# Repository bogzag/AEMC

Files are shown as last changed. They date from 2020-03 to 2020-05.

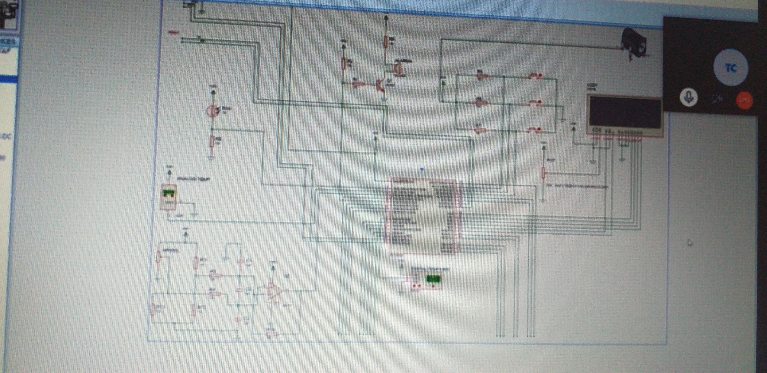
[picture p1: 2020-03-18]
PozeProiect/Schematic/20200318_112239.jpg

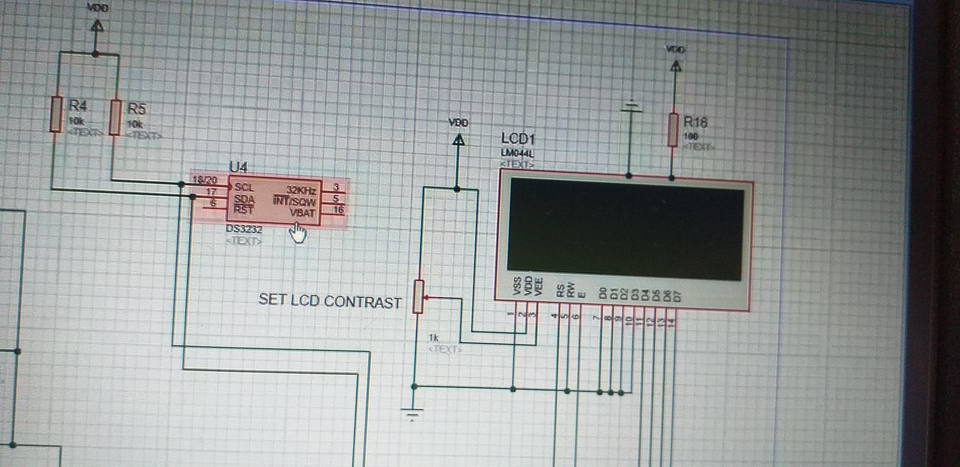
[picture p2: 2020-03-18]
PozeProiect/Schematic/20200318_110541.jpg

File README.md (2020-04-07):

# AEMC PROJECT:v:
The task is to create a meteo station (schematic, layout,code,hardware). 

Please upload your work in the correct section and add comments to avoid confusion between team members

Mention urgent tasks here and mark them with :exclamation:

Mark wrong info like this  ~~This info wrong my man~~

### Team members:sleeping:

@bogzag

@ClaudiaGitH

@alexandruf98

### Pt curs/proiect
(https://join.skype.com/lMuimAnFgpZ3?fbclid=IwAR00U5oWaqc2DzT4iKskiz9u4dI-uODVIiYZsmZv1TnuRMnrCDzAk37EaNk)

:exclamation: Layout+Code

### $ Lista de cumparaturi:
https://docs.google.com/spreadsheets/d/1xGkr67w3PWWBnmwl580I28Ox6pwAhuXMNzGf5ZXCvtU/edit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

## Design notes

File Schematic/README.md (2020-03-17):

# Schematic for AEMC PROJECT , done in PROTEUS v8.0

-All schematic versions must be done in Proteus version 8.0, newer versions might not be compatible

-Download and present the last uploaded version. Work only on the newer version of the schematic

-Add comments on changes, so all users know what issues are solved : 

## Task list:yum:
[ ]add changes after the project session

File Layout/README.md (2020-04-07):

# Layout for AEMC PROJECT, done in 

## Task list:yum:

- De finalizat partea cu senzorul de umiditate si amplificarea
- De ingrosat putin mai mult traseele (acum sunt 0.8 mm)

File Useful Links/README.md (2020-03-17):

# Useful Links for the project:paperclip:

Please mention if the resource is for a component or a tutorial, so we avoid wasting time wjile looking for info

## Components

https://www.olimex.com/Products/Modules/PIC-ICSP-Connector/ 

https://www.isweek.com/product/humidity-sensitive-resistor-hr202l_2691.html

https://cleste.ro/modul-usb-catre-ttl-cu-jumper.html

## Tutorials

https://exploreembedded.com/wiki/Serial_Communication_with_PIC16F877A

https://circuitdigest.com/microcontroller-projects/uart-communication-using-pic16f877a

https://www.youtube.com/watch?time_continue=35&v=idJEMYhrIfs&feature=emb_logo

## DataSheets

https://datasheets.maximintegrated.com/en/ds/DS1307.pdf

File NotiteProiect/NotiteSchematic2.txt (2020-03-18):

*Run Simulation
*We should create a simulation to see if all sensors
*A student per function
*Sa vedem care sunt valorile de rezistenta corespunzatoare starii de intuneric si lumina
max 5 v la luminanta maxima
nu trebie sa se satureze rezistenta R4 rezistenta mare
*Buzzer daca este functional la un curent de 0.5 miliamperi R6-un tranzistor cotr din microcontroler si tranzistorul sa aiba un buzzer in colector
*Putem incepe sa cream rutine soft
*Layoutul pt mufa de alimentare schimbat
*C-se opune variatilor rapide de tensiune
	-C2 : R4+fotorezis= divizor rezistiv
	-filtre blala frecventa de taiere 10 hz
	-o variatie lenta a luminii
	-o citire? a senzorului de 10 ori pe secunda
	-umbrele care apar temporar sa nu fie sesizate
	-putem filtra valorile din soft
	-LE TRATAM CA UN FILTRU RC CU FRECVENTA DE TAIERE FOARTE JOASA
	-CU CAT F DE TAIERE E MAI MICA, SENSIBILITATEA SCADE FOARTE MULT

*impartiti task urile
*cineva layout
*cineva soft
*cineva de simulare
*apoi hardware

daca e bipolar rez in baza si in colector
daca e mos nu punem nimic

*****De aici notite ciordite  de la celelalte scheme****
Catod la masa-la LCD
Anod-R100k-VDD
Tranzistor MOS 2N2222
Alegem fotorezistor si apoi calculam rezistenta de pulldown
FILTRE RC CA SA NE APARAM DE PARAZITI IN MORTII EI DE TREABA
rezistenta la UA741 nu mai stiu unde
I2C-REZISTENTE DE 10K PULLUP

tensiunea pe intrarea pozitiva-amplificare pozitiva-amplificare
butoanele sunt conectate gresit
lm35 e ok
rtc e ok
lcd alimentare de background
FILTRE RC LA TOT POPORUUUUL

butoanele gresit-condensatoare de 100nano in paralel cu butoanele
rezistentele recalculate
rezistenta in baza ca e bipolar la buzzer-R3 prea mare ar trebui sa fie de 100ohmi
lm35 folosit
LCD contrast E OK ACI
CREATI LAYOUT LA MUFA DE ALIMENTARE DACA NU E

Puntea Wiston are o diferenta de potential care trebuienampl
pornim calculul de la senzor de umiditate
Nu e corecta puntea wiston
nici senzorul
CONDENSATOARE IN PARALEL CU BUTOANELE
RTC REZISTENTE DE PULLUP
IN LAYOUT NUMELE STUDENTILOOOOOOR

eMITOR LA GROUND, BUZZER IN COLECT
Rezistor in serie cu buzzer

Sa lucram doar pe partea de BOTTOM A PCB ului
Nume PreNUME PE pcb
Nu folositi fire subtiri, minim 0.5 milimetrii grosimea firelor de conectare

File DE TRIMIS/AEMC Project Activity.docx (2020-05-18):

AEMC PROJECT ACTIVITY REPORT

TEAM1 - Group 5311

Bogza Gabriel - Realization of the PCB

Used KiCad to create the layout for the PCB

Searching for footprints

Design the layout

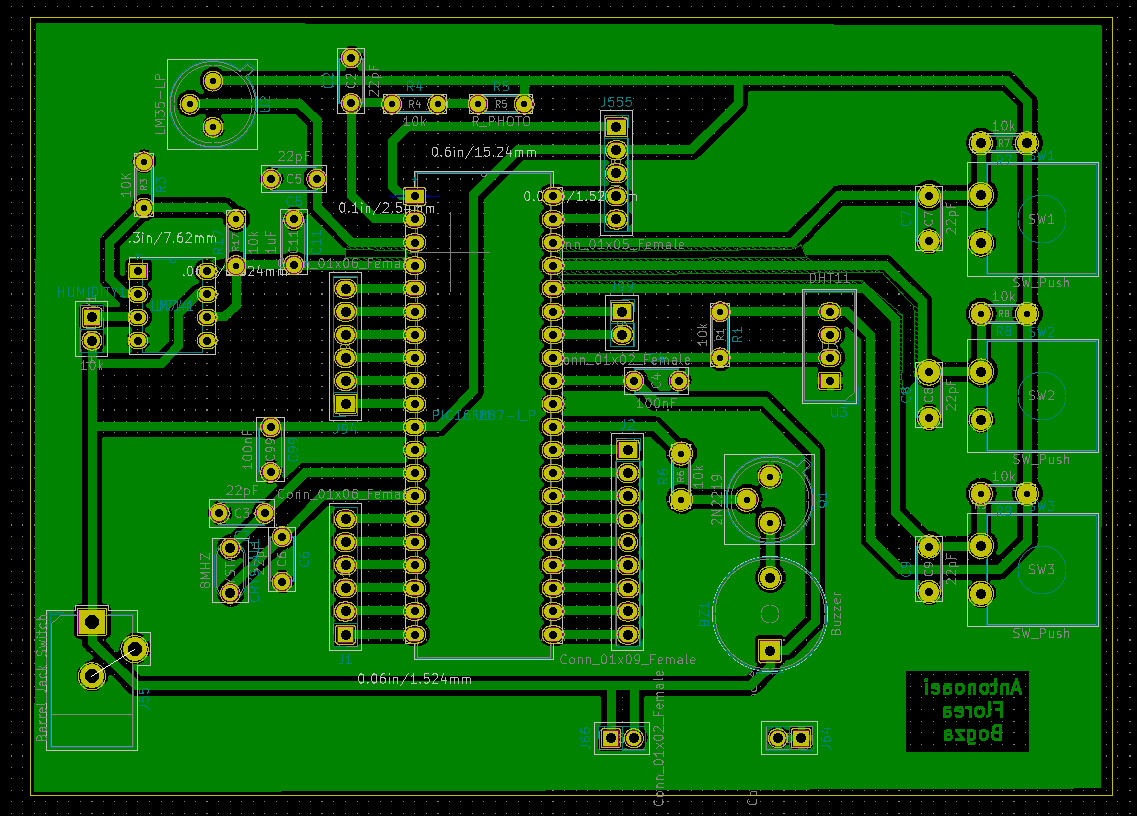
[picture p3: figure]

3D simulation:

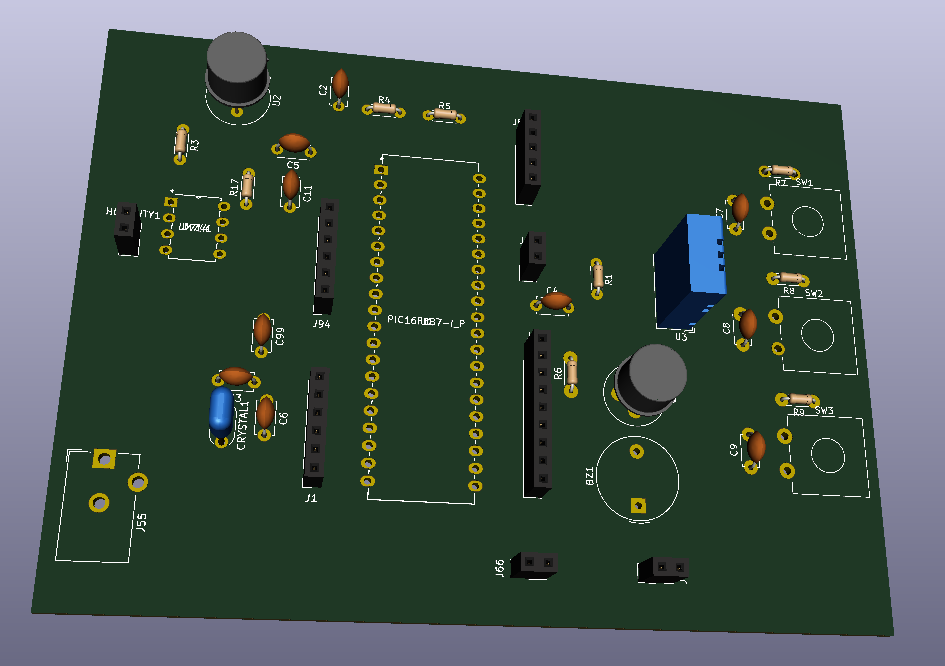
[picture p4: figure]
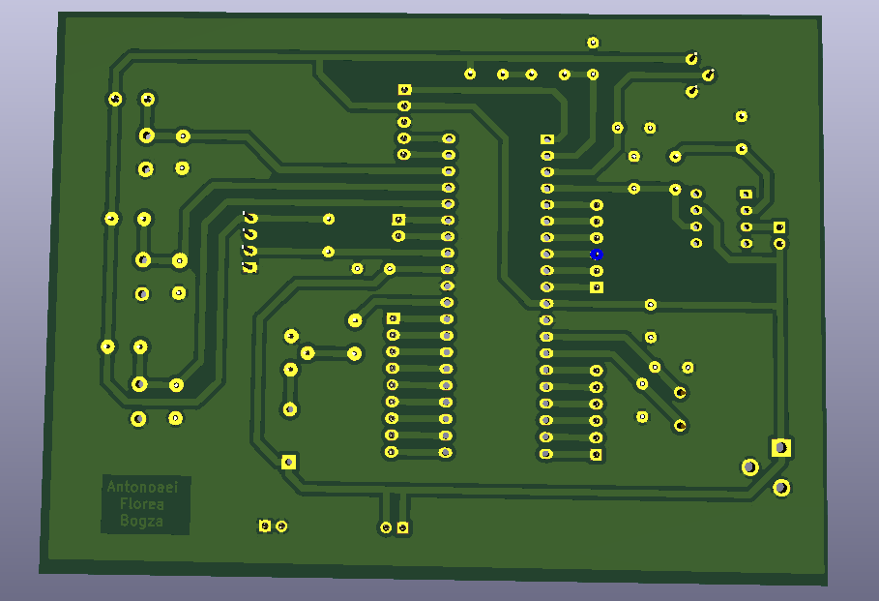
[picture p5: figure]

Order the components.

Multiple attempts to print the layout because the printer does not respect the sizes of pins.

Transfer the layout on the copper plate using the acetone and magazine paper method.

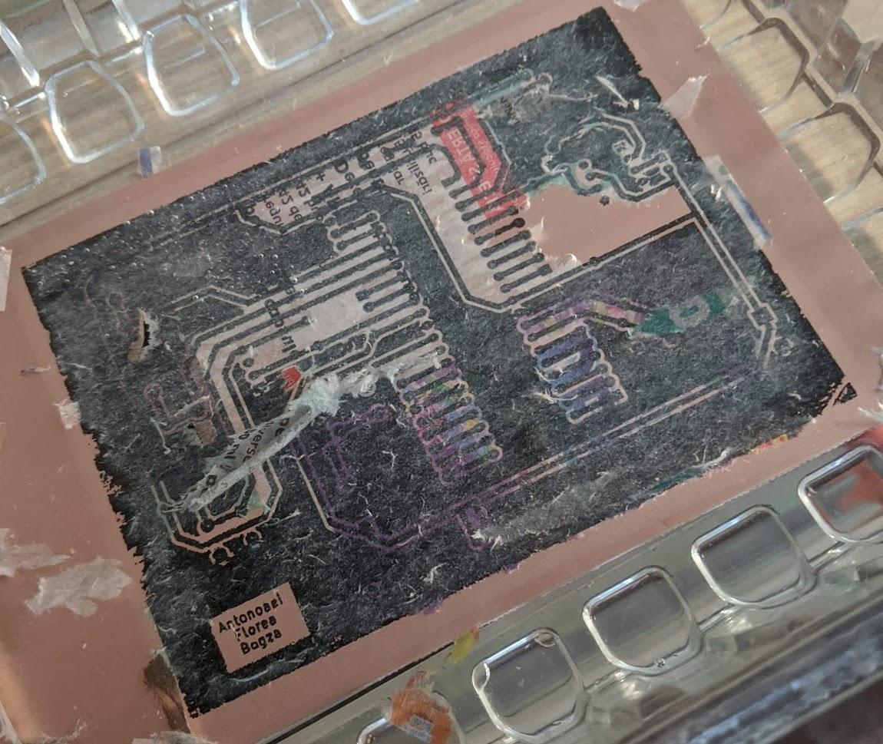
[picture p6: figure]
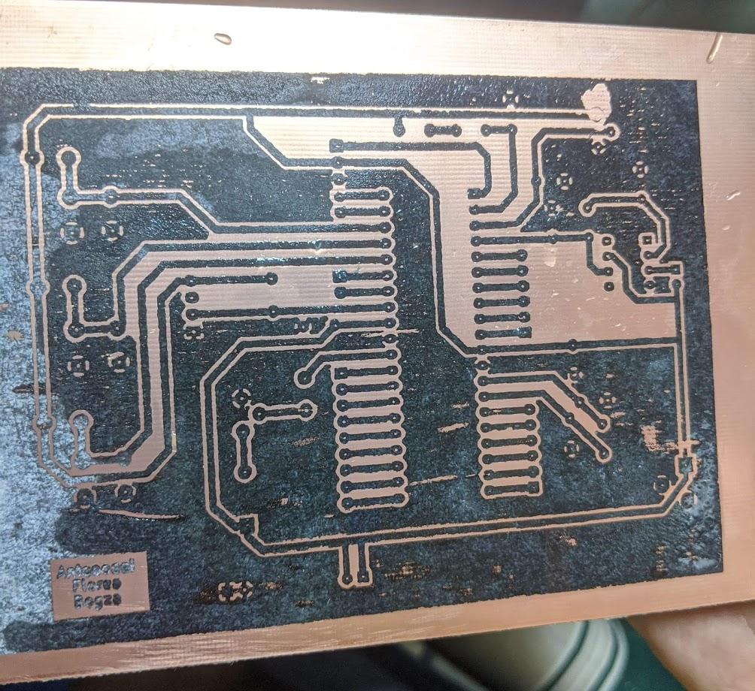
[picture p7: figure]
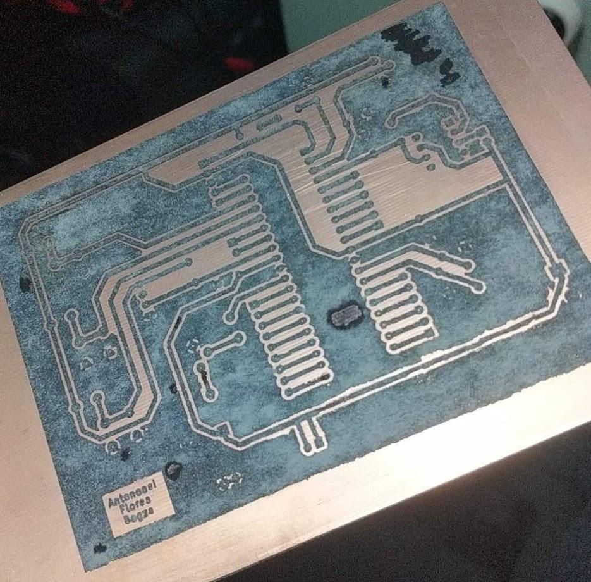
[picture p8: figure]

I corroded the PCB using ferric chloride.

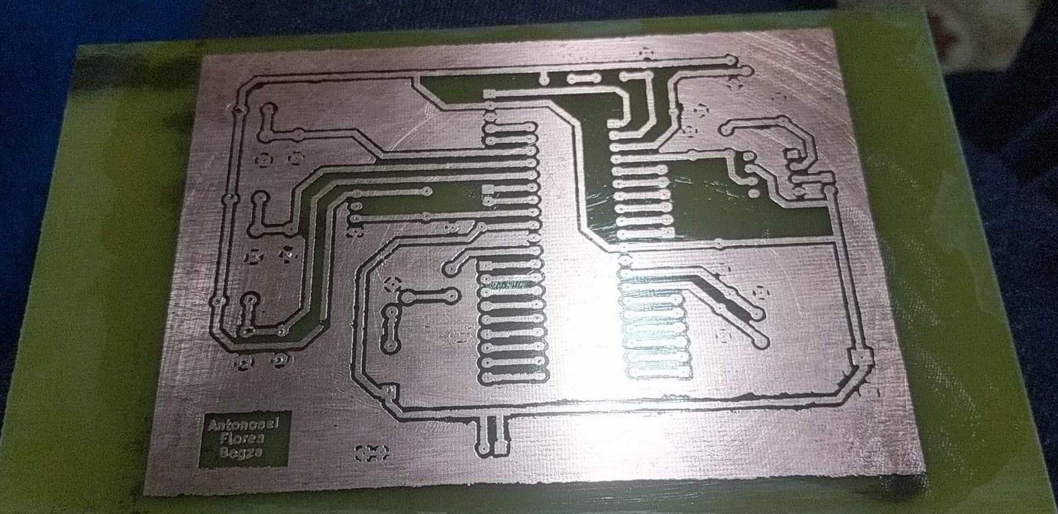
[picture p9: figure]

I drilled holes in the PCB to be able to add the components.

Soldered the components on the PCB

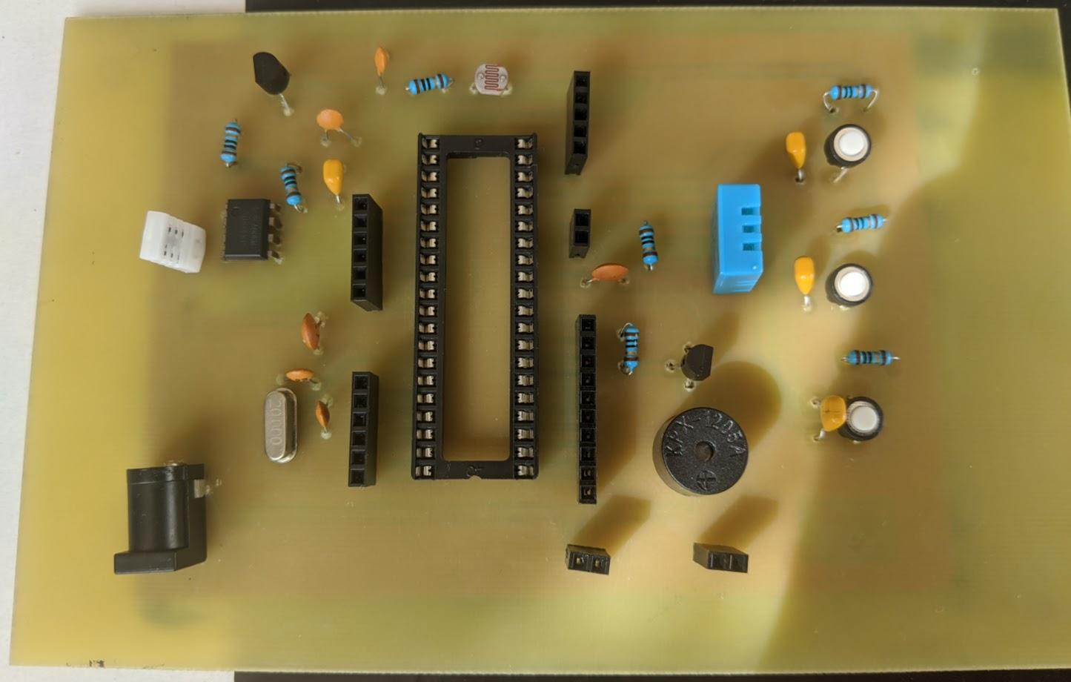
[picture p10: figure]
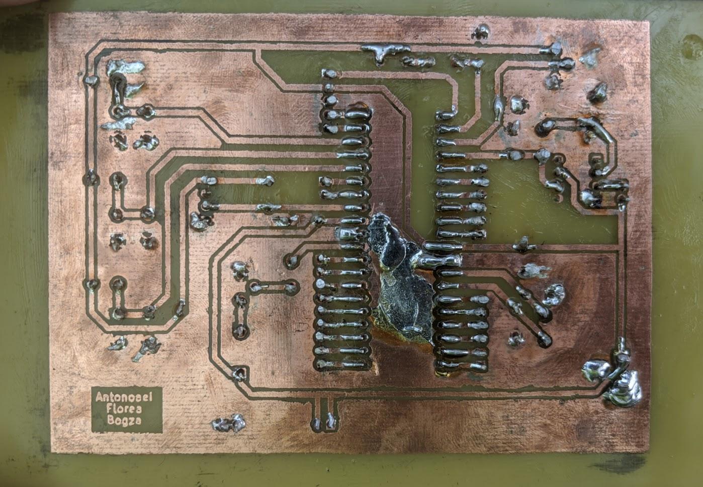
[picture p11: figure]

Antonoaei Claudia-Schematic and code for Real Time clock

I used Proteus 8.0 for my part. Dht11 can’t be found in Proteus 8.0 so we added it in 8.1.

This is the final schematic we used

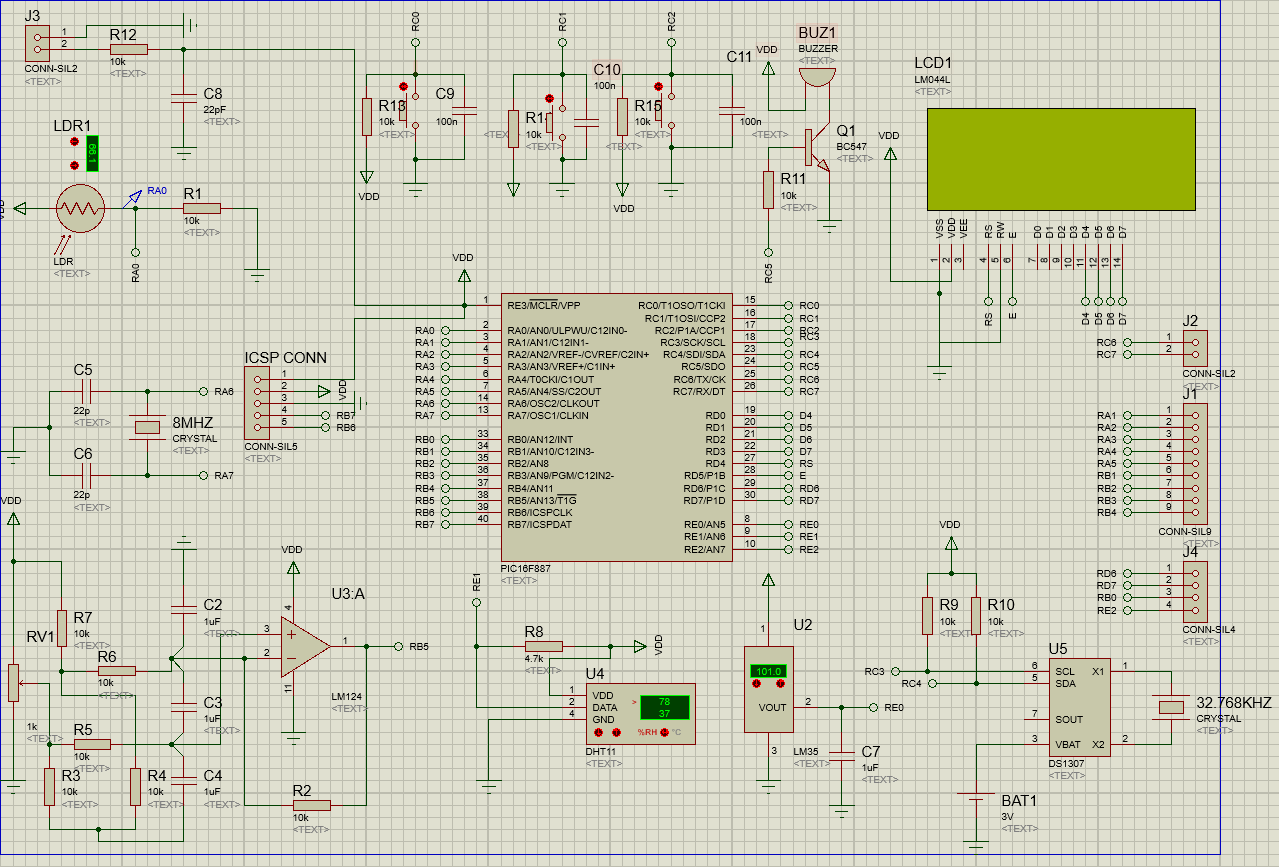
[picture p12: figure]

It should be noted that for the final code for the analog humidity sensor we used this schematic for testing, instead of the version of the amplifier in the last image.

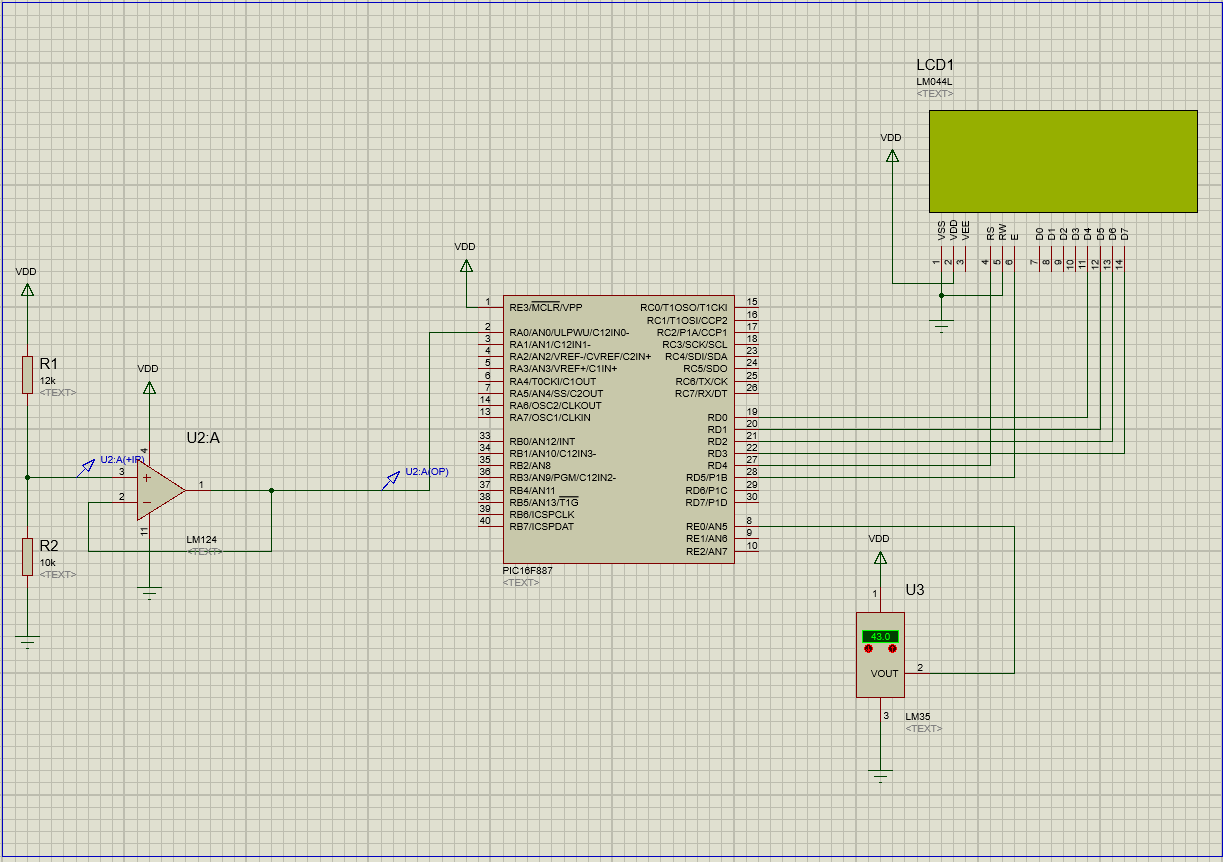
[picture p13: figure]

For the schematic, all colleagues made updates as necessary along the way.

For the code part I used Proteus 8.0. I did the code for the real time clock.

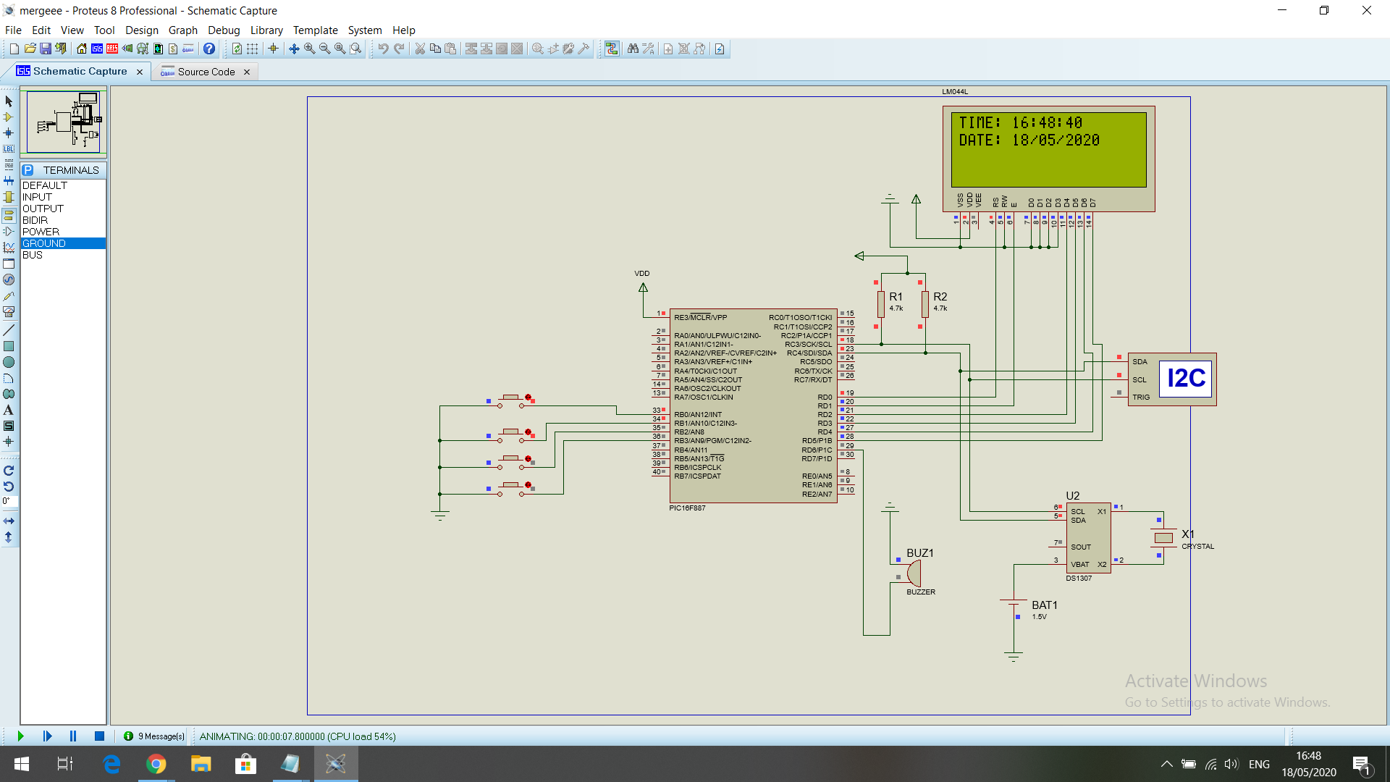
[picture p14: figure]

As you can see from the image, the real time clock is functional. Below I will list the code that I attached as well in the sent folder. This was not the first attempt at this, in fact it took several tries to make it work.

The used component for this particular simulation was DS1307 REAL TIME CLOCK.

#pragma config CONFIG1 = 0x2CD4

#pragma config CONFIG2 = 0x0700

#define button1 RB0

#define button2 RB1

#define buttonA1 RB2

#define buttonA2 RB3

#define LCD_RS RD0

#define LCD_EN RD1

#define LCD_D4 RD2

#define LCD_D5 RD3

#define LCD_D6 RD4

#define LCD_D7 RD5

#define LCD_RS_DIR TRISD0

#define LCD_EN_DIR TRISD1

#define LCD_D4_DIR TRISD2

#define LCD_D5_DIR TRISD3

#define LCD_D6_DIR TRISD4

#define LCD_D7_DIR TRISD5

#include <xc.h>

#define _XTAL_FREQ 8000000

#include <stdint.h>

#include <xc.h>

#include <stdio.h>

#include <string.h>

uint8_t i, second, minute, hour, m_day, month, year;

void LCD_Write_Nibble(uint8_t n);

void LCD_Cmd(uint8_t Command);

void LCD_Goto(uint8_t col, uint8_t row);

void LCD_PutC(char LCD_Char);

void LCD_Print(char* LCD_Str);

void LCD_Begin();

/********************** I2C functions **************************/

void I2C_Init(uint32_t i2c_clk_freq)

{

SSPCON = 0x28;

SSPADD = (_XTAL_FREQ/(4 * i2c_clk_freq)) - 1;

SSPSTAT = 0;

}

void I2C_Start()

{

while ((SSPSTAT & 0x04) || (SSPCON2 & 0x1F));

SEN = 1;

}

void I2C_Repeated_Start()

{

while ((SSPSTAT & 0x04) || (SSPCON2 & 0x1F));

RSEN = 1;

}

void I2C_Stop()

{

while ((SSPSTAT & 0x04) || (SSPCON2 & 0x1F));

PEN = 1;

}

void I2C_Write(uint8_t i2c_data)

{

while ((SSPSTAT & 0x04) || (SSPCON2 & 0x1F));

SSPBUF = i2c_data;

}

uint8_t I2C_Read(uint8_t ack)

{

uint8_t _data;

while ((SSPSTAT & 0x04) || (SSPCON2 & 0x1F));

RCEN = 1;

while ((SSPSTAT & 0x04) || (SSPCON2 & 0x1F));

_data = SSPBUF;

while ((SSPSTAT & 0x04) || (SSPCON2 & 0x1F));

ACKDT = !ack;

ACKEN = 1;

return _data;

}

/********************** end I2C functions **********************/

// a small function for button1 (B1) debounce

__bit debounce ()

{

uint8_t count = 0;

for(uint8_t i = 0; i < 5; i++) {

if (button1 == 0)

count++;

__delay_ms(10);

}

if(count > 2) return 1;

else return 0;

}

/********************** RTC chip functions *********************/

uint8_t bcd_to_decimal(uint8_t number) {

return((number >> 4) * 10 + (number & 0x0F));

}

uint8_t decimal_to_bcd(uint8_t number) {

return(((number / 10) << 4) + (number % 10));

}

void RTC_display()

{

static char Time[] = "TIME: 00:00:00";

static char Date[] = "DATE: 00/00/2000";

second = bcd_to_decimal(second);

minute = bcd_to_decimal(minute);

hour = bcd_to_decimal(hour);

m_day = bcd_to_decimal(m_day);

month = bcd_to_decimal(month);

year = bcd_to_decimal(year);

Time[6] = hour / 10 + '0';

Time[7] = hour % 10 + '0';

Time[9] = minute / 10 + '0';

Time[10] = minute % 10 + '0';

Time[12] = second / 10 + '0';

Time[13] = second % 10 + '0';

Date[6] = m_day / 10 + '0';

Date[7] = m_day % 10 + '0';

Date[9] = month / 10 + '0';

Date[10] = month % 10 + '0';

Date[14] = year / 10 + '0';

Date[15] = year % 10 + '0';

LCD_Goto(1, 1);

LCD_Print(Time);

LCD_Goto(1, 2);

LCD_Print(Date);

}

void blink()

{

uint8_t j = 0;

while(j < 100 && button1 && button2) {

j++;

__delay_ms(5);

}

}

uint8_t edit(uint8_t x, uint8_t y, uint8_t parameter)

{

while(debounce());

while(1) {

while(!button2)

{

parameter++;

if(i == 0 && parameter > 23)

parameter = 0;

if(i == 1 && parameter > 59)

parameter = 0;

if(i == 2 && parameter > 31)

parameter = 1;

if(i == 3 && parameter > 12)

parameter = 1;

if(i == 4 && parameter > 99)

parameter = 0;

LCD_Goto(x, y);

LCD_PutC(parameter / 10 + '0');

LCD_PutC(parameter % 10 + '0');

__delay_ms(200);

}

LCD_Goto(x, y);

blink();

LCD_Goto(x, y);

LCD_PutC(parameter / 10 + '0');

LCD_PutC(parameter % 10 + '0');

blink();

if(!button1)

if(debounce())

{

i++;

return parameter;

}

}

return 0;

}

/********************** end RTC chip functions *****************/

/*************************** main function *********************/

void main(void)

{

OSCCON = 0X70;

ANSELH = 0;

nRBPU = 0;

WPUB = 0x03;

__delay_ms(1000);

I2C_Init(100000);

LCD_Begin();

while(1) {

if(!button1)

if(debounce())

{

i = 0;

hour = edit(7, 1, hour);

minute = edit(10, 1, minute);

m_day = edit(7, 2, m_day);

month = edit(10, 2, month);

year = edit(15, 2, year);

while(debounce());

minute = decimal_to_bcd(minute);

hour = decimal_to_bcd(hour);

m_day = decimal_to_bcd(m_day);

month = decimal_to_bcd(month);

year = decimal_to_bcd(year);

I2C_Start();

I2C_Write(0xD0);

I2C_Write(0);

I2C_Write(0);

I2C_Write(minute);

I2C_Write(hour);

I2C_Write(1);

I2C_Write(m_day);

I2C_Write(month);

I2C_Write(year);

I2C_Stop();

__delay_ms(200);

}

I2C_Start();

I2C_Write(0xD0);

I2C_Write(0);

I2C_Repeated_Start();

I2C_Write(0xD1);

second = I2C_Read(1);

minute = I2C_Read(1);

hour = I2C_Read(1);

I2C_Read(1);

m_day = I2C_Read(1);

month = I2C_Read(1);

year = I2C_Read(0);

I2C_Stop();

RTC_display();

__delay_ms(50);

}

}

Below, I will list the modified functions for the alarm as well

void alarms_read_display() // read and display alarm1 and alarm2 data function

{

I2C_Start();

I2C_Write(0xD0);

I2C_Write(0x08);

I2C_Repeated_Start();

I2C_Write(0xD1);

alarm1_minute = I2C_Read(1);

alarm1_hour = I2C_Read(1);

I2C_Read(1);

I2C_Read(1);

I2C_Read(1);

control_reg = I2C_Read(1);

status_reg = I2C_Read(1);

I2C_Read(1);

I2C_Read(1);

I2C_Read(1);

I2C_Stop();

alarm1_minute = bcd_to_decimal(alarm1_minute);

alarm1_hour = bcd_to_decimal(alarm1_hour);

Alarm1[8] = alarm1_minute % 10 + '0';

Alarm1[7] = alarm1_minute / 10 + '0';

Alarm1[5] = alarm1_hour % 10 + '0';

Alarm1[4] = alarm1_hour / 10 + '0';

}

__bit debounce (uint8_t button)

{

uint8_t count = 0;

for(uint8_t i = 0; i < 5; i++)

{

switch (button)

{

case 1: if (button1 == 0)

count++;

break;

case 3: if (buttonA1 == 0)

count++;

break;

default: break;

}

__delay_ms(10);

}

if(count > 2) return 1;

else return 0;

}

void alarm_check(){

if((alarm1_minute == ((minute & 0x0F) + (minute >> 4) * 10)) &&

(alarm1_hour == ((hour & 0x0F) + (hour >> 4) * 10)) && (second == 0))

Buzzer=1;

}

Alexandru Florea-code

Code for humidity sensor:

/*Template Proiect AEMC - ETTI Iasi*/

#include <xc.h>

__PROG_CONFIG(1,0x20D4); // config. uC

__PROG_CONFIG(2,0x0000); // config. uC

#define LED1 RB0

#define LED2 RB1

#define _XTAL_FREQ 8000000

char *stringumid = (char *) "umiditate analogica";

void init_uC(void);

void interrupt etti(void); // functie de intreruperi globala ptr. TOATE intreruperile de pe un

void init_LCD(void);

void lcd_goto(unsigned char pos);

void lcd_puts(char * s);

void lcd_putch(char c);

void senzumid(void);

unsigned int Citeste_ADC(unsigned char canal);

int temperatura[] = {0,5,10,15,20,25,30,35,40,45,50};

const double matricetabel[11][15] = {

{0, 0, 12000, 5200, 2800, 720, 384, 200, 108, 64, 38, 23, 16 ,10.2,6.9},

{0, 19800, 9800, 4700, 2000, 510, 271, 149, 82, 48, 29, 18, 12, 8.2, 5.4},

{0, 16000, 7200, 3200, 1400, 386, 211, 118, 64, 38, 24, 15, 10.2, 6.9, 4.7},

{21000, 10500, 5100, 2350, 1050, 287, 159, 91, 51, 31, 19, 12, 8.1, 5.5, 4.1},

{13500, 6700, 3300, 1800, 840, 216, 123, 70, 40, 25, 16, 10, 7.2, 4.7, 3.2},

{9800, 4803, 2500, 1300, 630, 166, 95, 55, 31, 20, 13, 8.5, 5.7, 4.0, 2.8},

{8000, 3900, 2000, 980, 470, 131, 77, 44, 25, 17, 10.5, 7.2, 5.0, 3.6, 2.5},

{6300, 3100, 1500, 750, 385, 104, 63, 38, 21, 13, 9, 6.4, 4.4, 3.2, 2.3},

{4600, 2300, 1100, 575, 282, 80, 52, 32, 17, 11, 8.2, 5.8, 4.0, 2.9, 2.1},

{3800, 1850, 900, 430, 210, 66, 45, 30, 14, 9, 7.1, 5.0, 3.3, 2.4, 1.8},

{3200, 1550, 750, 350, 170, 51, 38, 24, 12, 8, 6.0, 4.1, 2.9, 2.0, 1.5},

};

int umid[]={20,25,30,35,40,45,50,55,60,65,70,75,80,85,90};

void main(void)

{

init_uC();

init_LCD();

while (1)

{

senzumid();

}

}

void init_uC (void)

{

OSCCON = 0x71; // setez Osc. intern uC de 8MHz // pag. 64

ANSELH = 0x00;

ADCON0 = 0b10000001;

ADCON1 = 0x80;

T1CON=0x10;

TMR1H=0;

TMR1L=0;

TRISA = 0x01;

TRISB = 0x00;

TRISC = 0x01;

TRISD = 0x00;

TRISE = 0b00000011;

ANSEL = 0b00000001;

PORTB = 0b00000000; // initializez PORTB cu valori de 0 logic

OPTION_REG = 0b00000111;// Frecv. intrare T0 = Frecv. Osc./4 (=8MHz/4) = 2MHz

// prescaler=256 => Frecv. T0 = 2MHz/256 = KHz (sau T=128us)

TMR0IF = 0; //

TMR0 = 178; // porneste numararea de la valoarea 178; pana la maxim (255)

TMR0IE = 1; // activez intreruperea ptr. T0

GIE = 1; // activez Global intreruperile

}

void interrupt etti(void) // ajung aici la fiecare 78*128us=~10ms

{

if(TMR0IF) // daca flagul TMR0IF=1

{

TMR0IF = 0; // obligatoriu - sterg flagul Timerului care a generat intreruperea

TMR0 = 178; //

LED2 = !LED2; //

}

}

unsigned int Citeste_ADC(unsigned char canal)

{

if(canal > 13)

return 0;

ADCON0 &= 0xC3;

ADCON0 |= (canal << 2);

__delay_ms(100);

GO_nDONE = 1;

while(GO_nDONE);

return ((ADRESH<<8)+ADRESL);

}

void senzumid(void)

{

int temptabel = 1, umidtabel = 0;

float templm;

templm = Citeste_ADC(5);

templm = templm*4.882;

templm=templm/10.0;

int i;

for(i=0;i<=10;i++)

{ if(templm>=temperatura[i])

{

temptabel++;

}

}

float imp;

imp = Citeste_ADC(0);

imp=imp*4.882;

imp=imp/1000.0;

imp = (10.0*(5-imp)/imp);

if(temptabel==0)

{

umidtabel=2;

}

if(temptabel == 1)

{

umidtabel=1;

}

if(temptabel == 2)

{

umidtabel=1;

}

while(imp<=matricetabel[temptabel][umidtabel])

{

umidtabel++;

}

int val=(int)umid[umidtabel];

__delay_ms(2);

lcd_goto(0x80);

__delay_ms(2);

lcd_puts(stringumid);

lcd_goto(0xC0);

lcd_putch((val/10)%10+'0');

__delay_ms(2);

lcd_putch((val)%10+'0');

__delay_ms(2);

lcd_putch('%');

}

Code for LM35,photoresistor+DHT11

/*Template Proiect AEMC - ETTI Iasi*/

#include <xc.h>

#include<math.h>

__PROG_CONFIG(1,0x20D4); // config. uC

__PROG_CONFIG(2,0x0000); // config. uC

#define _XTAL_FREQ 8000000

#define LED2 RB1

#define butoninc RC2

#define butonalarm RC1

#define butontimp RC0

#define dhtpin RE1

#define dhtpin_dir TRISE1

char *tempanalog = (char *) " Temperatura LM35";

char *luminanalog = (char *) "luminozitate";

char *tempdht = (char *) "temp dht";

char *umiddht = (char *) "umid dht";

char *pag1 = (char *) "pagina 1";

char *pag2 = (char *) "pagina 2";

char *pag3 = (char *) "pagina 3";

char *lum = (char *) "lumeni/m^2";

void init_uC(void);

void interrupt etti(void); // functie de intreruperi globala ptr. TOATE intreruperile de pe un

void init_LCD(void);

void lcd_goto(unsigned char pos);

void lcd_puts(char * s);

void lcd_putch(char c);

void lcd_clear(void);

void lm35(void);

void luminozitate(void);

void initializare_dht(void);

unsigned short raspuns_dht(void);

unsigned short citire_dht(unsigned short *);

void afisare_dht(void);

void afisarepag(void);

unsigned int Citeste_ADC(unsigned char canal);

char temperatura[]="temperatura = 00.0C";

char umiditate[]="umiditate = 00.0%";

unsigned short tempbyte1, tempbyte2, umidbyte1, umidbyte2, suma;

void main(void)

{

init_uC();

init_LCD();

while(1)

{

afisarepag();

}

}

void init_uC (void)

{

OSCCON = 0x71; // setez Osc. intern uC de 8MHz // pag. 64

ADCON0 = 0b10000001;

ADCON1 = 0x80;

T1CON=0x10;

TMR1H=0;

TMR1L=0;

TRISA = 0x01;

TRISB = 0x00;

TRISC = 0x00;

TRISD = 0x00;

TRISE = 0b00000011;

ANSEL = 0b00000001;

ANSELH = 0x00;

PORTB = 0b00000000; // initializez PORTB cu valori de 0 logic

OPTION_REG = 0b00000111;// Frecv. intrare T0 = Frecv. Osc./4 (=8MHz/4) = 2MHz

// prescaler=256 => Frecv. T0 = 2MHz/256 = KHz (sau T=128us)

TMR0IF = 0; //

TMR0 = 178; // porneste numararea de la valoarea 178; pana la maxim (255)

TMR0IE = 1; // activez intreruperea ptr. T0

GIE = 1; // activez Global intreruperile

}

unsigned int Citeste_ADC(unsigned char canal)

{

if(canal > 13)

return 0;

ADCON0 &= 0xC3;

ADCON0 |= (canal << 2);

__delay_ms(100);

GO_nDONE = 1;

while(GO_nDONE);

return ((ADRESH<<8)+ADRESL);

}

void lm35(void)

{

int adc,temp1,c1,c2,c3,c4;

float volt,temp;

adc=Citeste_ADC(5);

volt=adc*4.882;

temp=volt;

temp1=temp;

c1=(temp1/1000)%10;

c2=(temp1/100)%10;

c3=(temp1/10)%10;

c4=(temp1/1)%10;

__delay_ms(2);

lcd_goto(0xC1);

__delay_ms(2);

lcd_puts(tempanalog);

__delay_ms(2);

lcd_goto(0x99);

__delay_ms(2);

lcd_putch(c1+'0');

__delay_ms(2);

lcd_putch(c2+'0');

__delay_ms(2);

lcd_putch(c3+'0');

lcd_puts(".");

__delay_ms(2);;

lcd_putch(c4+'0');

__delay_ms(2);

lcd_putch(0xDF);

__delay_ms(2);

lcd_puts("C");

}

void luminozitate(void)

{

int adc,c1,c2,c3,c4;

float r1=10.0,curent;

float lv,lum,ressenz;

adc=Citeste_ADC(0);

lv=adc*4.882;

lv/=1000;

ressenz=(5-lv)/(lv/r1);

ressenz=(pow(10,5.07)*pow(ressenz,(-0.9)))/10;

int result=(int)ressenz;

c1=(result/1000)%10;

c2=(result/100)%10;

c3=(result/10)%10;

c4=(result/1)%10;

__delay_ms(2);

lcd_goto(0xC4);

__delay_ms(2);

lcd_puts(luminanalog);

__delay_ms(2);

lcd_goto(0x98);

__delay_ms(2);

lcd_putch(c1+'0');

__delay_ms(2);

lcd_putch(c2+'0');

__delay_ms(2);

lcd_puts(".");

__delay_ms(2);

lcd_putch(c3+'0');

__delay_ms(2);

lcd_putch(c4+'0');

__delay_ms(2);

lcd_puts("lumeni/m^2");

}

void initializare_dht(void)

{

dhtpin_dir = 0;

dhtpin = 0;

__delay_ms(25);

dhtpin = 1;

__delay_us(25);

dhtpin_dir = 1;

}

unsigned short raspuns_dht()

{

TMR1H = 0;

TMR1L = 0;

TMR1ON = 1;

while(!dhtpin && TMR1L < 100);

if(TMR1L > 99)

return 0;

else { TMR1H = 0;

TMR1L = 0;

while(dhtpin && TMR1L < 100);

if(TMR1L > 99)

{

return 0;

}

else

{

return 1;

}

}

}

unsigned short citire_dht(unsigned short* dhtdata)

{

short i;

*dhtdata = 0;

for( int i = 0; i < 8; i++)

{

TMR1H=0;

TMR1L=0;

while(!dhtpin)

{

if(TMR1L > 100)

{

return 1;

}

TMR1H = 0;

TMR1L = 0;

}

while(dhtpin)

if(TMR1L > 100)

if(TMR1L > 100)

{

return 1;

}

if(TMR1L > 50)

*dhtdata |=(1<<(7-i));

}

return 0;

}

void afisare_dht(void)

{

initializare_dht();

if(raspuns_dht())

{

if(citire_dht(&umidbyte1) || citire_dht(&umidbyte2) || citire_dht(&tempbyte1) || citire_dht(&tempbyte2) || citire_dht(&suma))

{

lcd_clear();

lcd_goto(0x80);

lcd_puts((char *) "eroare la citirea datelor");

}

else {

if(suma == ((umidbyte1 + umidbyte2 + tempbyte1 + tempbyte2) & 0xFF))

{

temperatura[14] = (tempbyte1/10 + 48);

temperatura[15] = (tempbyte1%10 + 48);

temperatura[17] = (tempbyte2/10 + 48);

umiditate[12] = (umidbyte1/10 + 48);

umiditate[13] = (umidbyte1%10 + 48);

umiditate[15] = (umidbyte2/10 + 48);

temperatura[18] = 223;

lcd_goto(0xC2);

lcd_puts(temperatura);

lcd_goto(0x96);

lcd_puts(umiditate);

}

else {

lcd_clear();

lcd_goto(0x80);

lcd_puts((char*) "verifica suma");

}

}

}

else {

lcd_goto(0x80);

lcd_puts((char*) "Niciun");

lcd_goto(0xC0);

lcd_puts((char*) "raspuns");

}

TMR1ON = 0;

__delay_ms(1000);

}

void afisarepag(void)

{

unsigned k=0;

do{

lcd_goto(0x86);

lcd_puts(pag1);

lm35();

k++;

}while(k<=50);

__delay_ms(100);

lcd_clear();

k=0;

do{

__delay_ms(10);

lcd_goto(0x86);

lcd_puts(pag2);

luminozitate();

k++;

}while(k<=50);

lcd_clear();

__delay_ms(10);

k=0;

do{

__delay_ms(10);

lcd_goto(0x86);

lcd_puts(pag3);

afisare_dht();

k++;

}while(k<=50);

lcd_clear();

__delay_ms(10);

k=0;

}

void interrupt etti(void) // ajung aici la fiecare 78*128us=~10ms

{

if(TMR0IF) // daca flagul TMR0IF=1

{

TMR0IF = 0; // obligatoriu - sterg flagul Timerului care a generat intreruperea

TMR0 = 178; //

LED2 = !LED2; //

}

}

The following table illustrates the calculus done for the luminosity sensor.

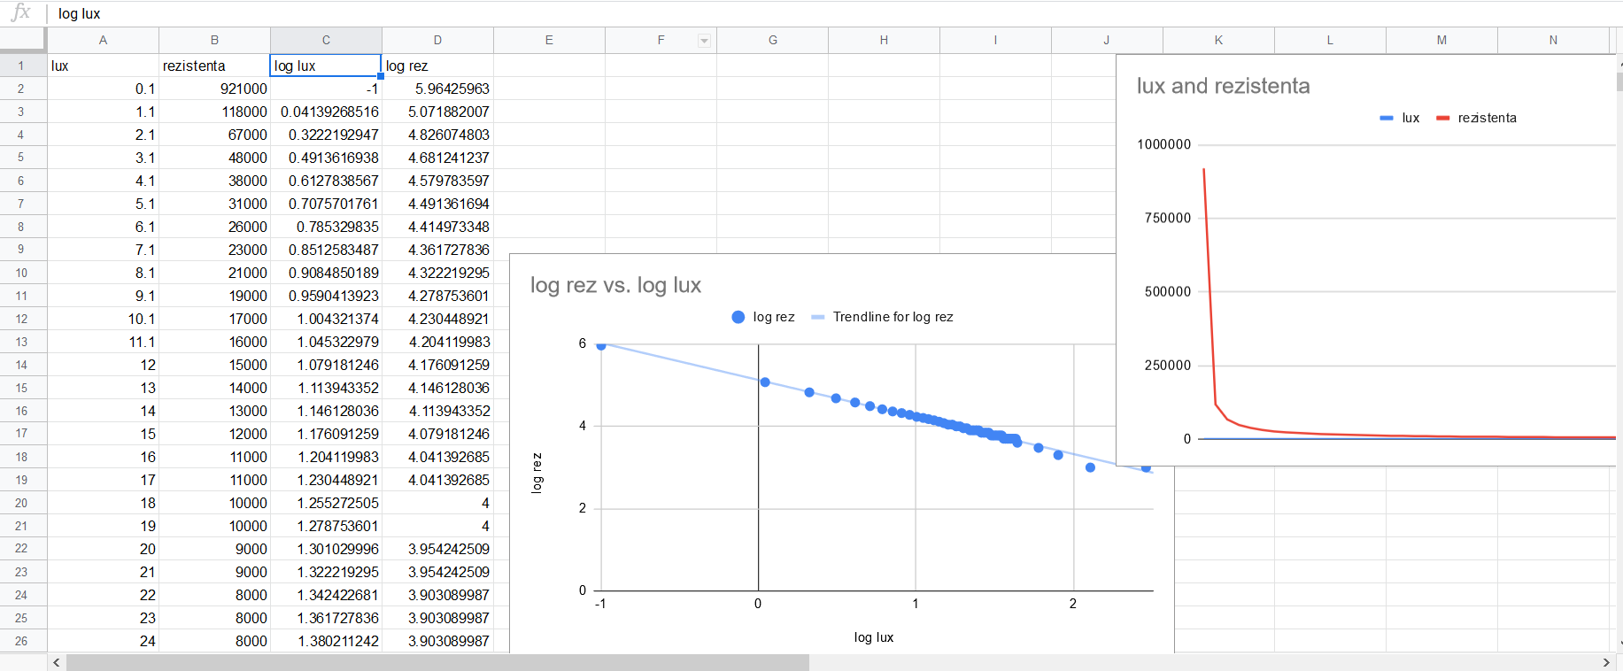
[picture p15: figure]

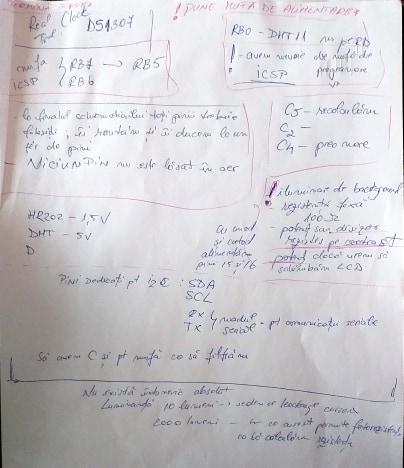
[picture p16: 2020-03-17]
NotiteProiect/Notes1.jpg

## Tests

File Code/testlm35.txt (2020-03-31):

/*Template Proiect AEMC - ETTI Iasi*/
#include <xc.h>

__PROG_CONFIG(1,0x20D4); 	// config. uC 
__PROG_CONFIG(2,0x0000); 	// config. uC 
#define _XTAL_FREQ 8000000
#define LED1 RB0 
#define LED2 RB1
#define butoninc RC2
#define butonalarm RC1
#define butontimp RC0

char *logo  = (char *) "AEMC - proiect LCD";
char *logo1 = (char *) "linia_1";
char *logo2 = (char *) "linia_2";
char *logo3 = (char *) "linia_3";
char *logo4 = (char *) "linia_4";
char *tempanalog = (char *) " Temperatura LM35";

void init_uC(void); 
void interrupt etti(void); 	// functie de intreruperi globala ptr. TOATE intreruperile de pe un 
void init_LCD(void);
void lcd_goto(unsigned char pos);
void lcd_puts(char * s);
void lcd_putch(char c);
void lcd_clear(void);

//void afisare_diacritice(unsigned char diacritic_afisat, unsigned char linia);
unsigned int Citeste_ADC(unsigned char canal);
//float conversietemp(float volt, int adctemp);

void main(void)
 { 
	int adc,temp1,c1,c2,c3,c4;
	float volt,temp;
	init_uC();
	init_LCD();

	 while(1)
	 {
	
		 adc=Citeste_ADC(5);
		 volt=adc*4.882;
		 temp=volt/10.0;
		 temp1=temp*100;
		 c1=(temp1/1000)%10;
		 c2=(temp1/100)%10;
		 c3=(temp1/10)%10;
		 c4=(temp1/1)%10;
		 lcd_clear();
		 lcd_goto(0x80);
		 lcd_puts(tempanalog);
		 lcd_goto(0xC0);
		 lcd_putch(c1+'0');
		 lcd_putch(c2+'0');
		 lcd_puts(".");
		 lcd_putch(c3+'0');
		lcd_putch(c4+'0');
		lcd_putch(0xDF);
		 lcd_puts("C");
		 __delay_ms(100);
	 
	 }

 }
 void init_uC (void) 
{ 	
	OSCCON 	= 0x71;			// setez Osc. intern uC de 8MHz // pag. 64
	ADCON0 = 0b10000001;
	ADCON1 = 0x80;
    TRISA = 0x00;//RA7,RA6,RA0 intrare
    TRISB = 0x00;//RB5,RB0 intrare
    TRISC = 0x00;//RB3,2,1 intrare(butoane)
    TRISD = 0x00;
    TRISE = 0x01;
    ANSEL = 0b00100000;
    ANSELH = 0x00;
	PORTB = 0b00000000;	// initializez PORTB cu valori de 0 logic
	OPTION_REG = 0b00000111;// Frecv. intrare T0 = Frecv. Osc./4 (=8MHz/4) = 2MHz
							// prescaler=256 => Frecv. T0 = 2MHz/256 = KHz (sau T=128us)
	TMR0IF 	= 0;			// 
	TMR0 	= 178;	  		// porneste numararea de la valoarea 178; pana la maxim (255) 
	TMR0IE 	= 1;    		// activez intreruperea ptr. T0
	GIE 	= 1;       		// activez Global intreruperile
	
} 
unsigned int Citeste_ADC(unsigned char canal)
{
   if(canal > 13)//an13 e ultimul pin analog
		return 0;
    ADCON0 &= 0xC3; //curat adcon0, setez adon on
    ADCON0 |= (canal << 2); //selectam canal ADC, 2 biti ca sa ajungem pe bitii canalului
    
    __delay_ms(100);//delay pt AD sa citeasca corect
        
    GO_nDONE = 1;
    while(GO_nDONE);//pauza pana cand A/D termina conversia
    return ((ADRESH<<8)+ADRESL);//returnez valoarea convertita
    
}

/*float conversiontemp(float volt,int adctemp)
{
	adctemp=Citeste_ADC(5)//citire valoare ADC pt LM35
	volt = adctemp*4.883;//5000mv/1023
	return volt;
}*/

/*void lcd_putc( char c) 
{
   switch (c) {
     case '\f'   : lcd_send_byte(0,1);
                   delay_ms(2);
                                           break;
     case '\n'   : lcd_gotoxy(1,2);        break;
     case '\b'   : lcd_send_byte(0,0x10);  break;
     default     : lcd_send_byte(1,c);     break;
   }
}*/

void interrupt etti(void)	// ajung aici la fiecare 78*128us=~10ms
{       
	if(TMR0IF)				// daca flagul TMR0IF=1
	{
		 TMR0IF = 0;   		// obligatoriu - sterg flagul Timerului care a generat intreruperea
		 TMR0 = 178;  		// 
		 LED2 = !LED2; 		// 
	}
}

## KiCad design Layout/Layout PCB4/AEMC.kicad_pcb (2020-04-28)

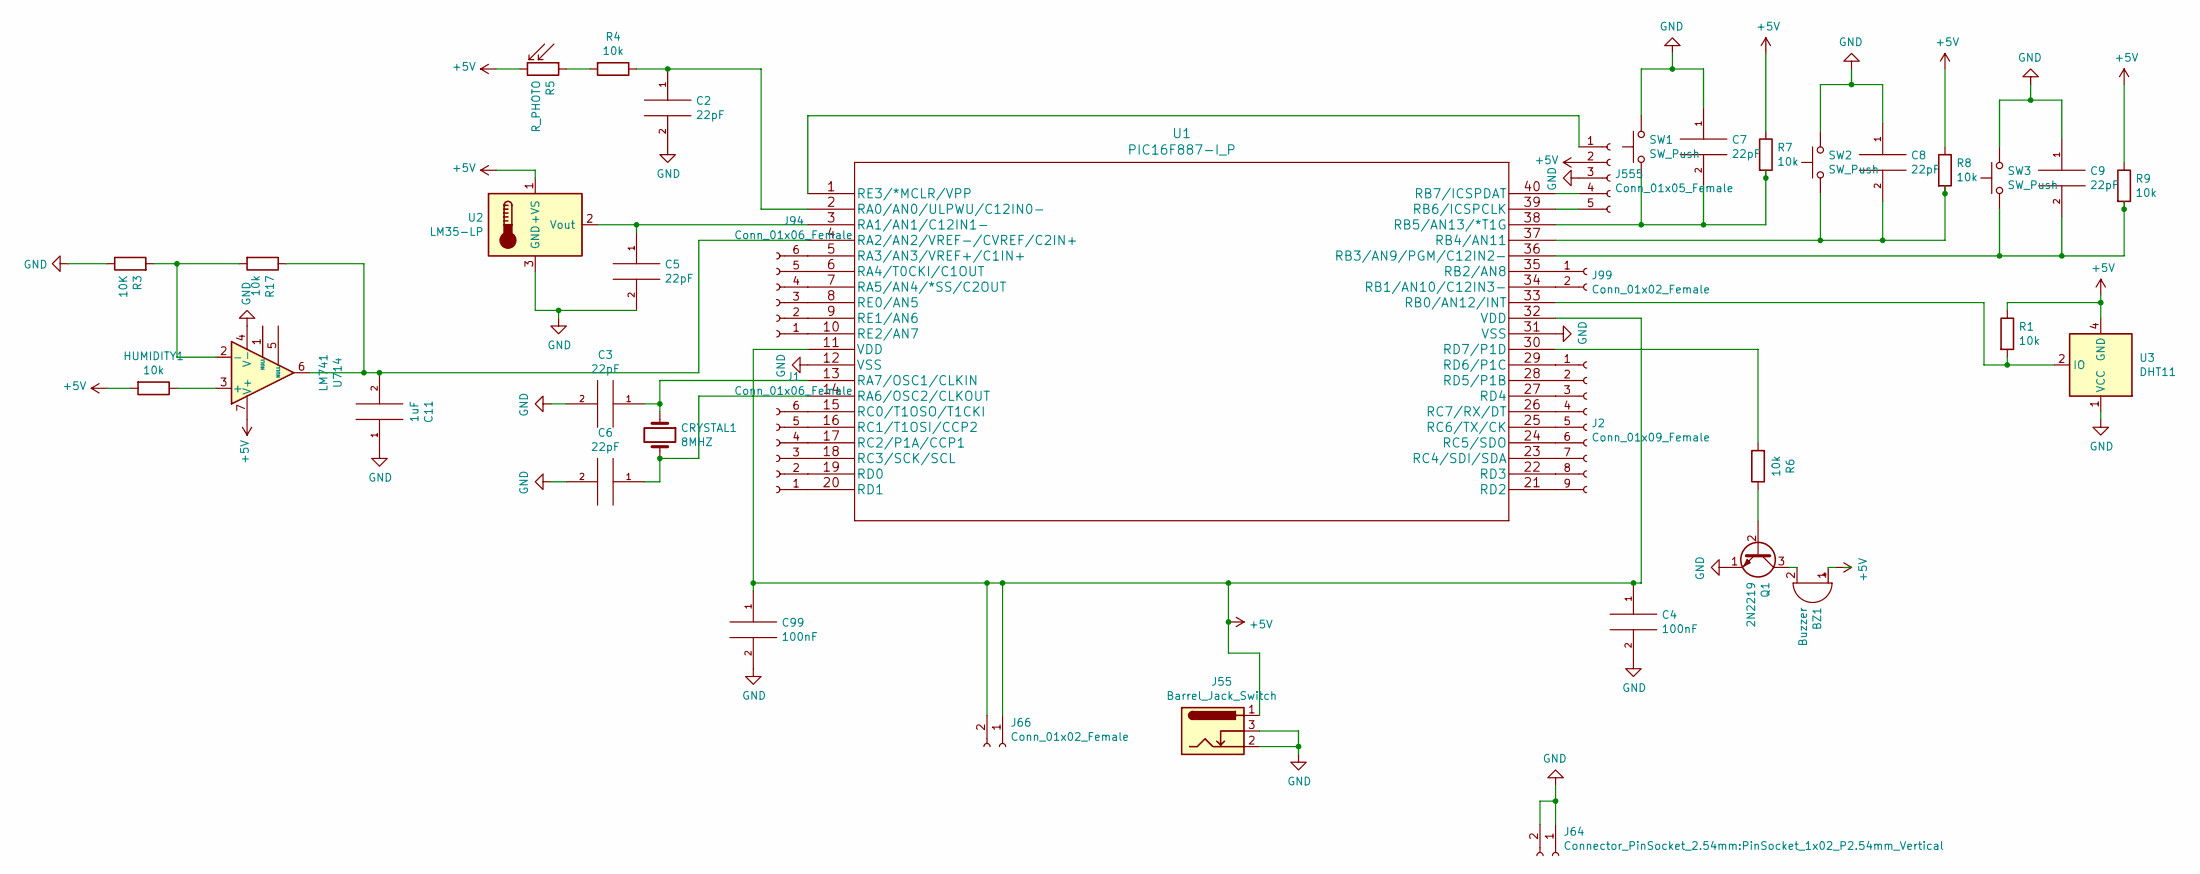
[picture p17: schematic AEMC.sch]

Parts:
BZ1: Buzzer; Buzzer_TDK_PS1240P02BT_D12.2mm_H6.5mm
C2, C3, C5, C6, C7, C8, C9: 22pF; C_Disc_D4.7mm_W2.5mm_P5.00mm
C4, C99: 100nF; C_Disc_D4.7mm_W2.5mm_P5.00mm
C11: 1uF; C_Disc_D4.7mm_W2.5mm_P5.00mm
CRYSTAL1: 8MHZ; Resonator-2Pin_W6.0mm_H3.0mm
HUMIDITY1: 10k; PinSocket_1x02_P2.54mm_Vertical
J1, J94: Conn_01x06_Female; PinSocket_1x06_P2.54mm_Vertical
J2: Conn_01x09_Female; PinSocket_1x09_P2.54mm_Vertical
J55: Barrel_Jack_Switch; BarrelJack_CUI_PJ-102AH_Horizontal
J64: Connector_PinSocket_2.54mm:PinSocket_1x02_P2.54mm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; PinSocket_1x02_P2.54mm_Vertical
J66, J99: Conn_01x02_Female; PinSocket_1x02_P2.54mm_Vertical
J555: Conn_01x05_Female; PinSocket_1x05_P2.54mm_Vertical
Q1: 2N2219; TO-39-3
R1, R4, R6, R7, R8, R9, R17: 10k; R_Axial_DIN0204_L3.6mm_D1.6mm_P5.08mm_Horizontal
R3: 10K; R_Axial_DIN0204_L3.6mm_D1.6mm_P5.08mm_Horizontal
R5: R_PHOTO; R_Axial_DIN0204_L3.6mm_D1.6mm_P5.08mm_Horizontal
SW1, SW2, SW3: SW_Push; SW_CW_GPTS203211B
U1: PIC16F887-I_P; PIC16F887-I&slash_P
U2: LM35-LP; TO-39-3
U3: DHT11; Aosong_DHT11_5.5x12.0_P2.54mm
U714: LM741; UA741CP

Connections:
+5V: BZ1.1 (-), C4.1, C99.1, HUMIDITY1.2, J55.1, J66.1, J66.2, J555.2, R1.1, R5.2, R7.1, R8.1, R9.1, U1.11 (VDD), U1.32 (VDD), U2.1 (+VS), U3.4 (GND), U714.7 (V+)
GND: C2.2, C3.2, C4.2, C5.2, C6.2, C7.1, C8.1, C9.1, C11.1, C99.2, J55.2, J55.3, J64.1, J64.2, J555.3, Q1.1 (E), R3.1, SW1.2, SW2.2, SW3.2, U1.12 (VSS), U1.31 (VSS), U2.3 (GND), U3.1 (VCC), U714.4 (V-)
unnamed: BZ1.2 (+), Q1.3 (C)
unnamed: C2.1, R4.1, U1.2 (RA0/AN0/ULPWU/C12IN0-)
unnamed: C3.1, CRYSTAL1.1, U1.13 (RA7/OSC1/CLKIN)
unnamed: C5.1, U1.3 (RA1/AN1/C12IN1-), U2.2 (Vout)
unnamed: C6.1, CRYSTAL1.2, U1.14 (RA6/OSC2/CLKOUT)
unnamed: C7.2, R7.2, SW1.1, U1.38 (RB5/AN13/*T1G)
unnamed: C8.2, R8.2, SW2.1, U1.37 (RB4/AN11)
unnamed: C9.2, R9.2, SW3.1, U1.36 (RB3/AN9/PGM/C12IN2-)
unnamed: C11.2, R17.1, U1.4 (RA2/AN2/VREF-/CVREF/C2IN+), U714.6
unnamed: HUMIDITY1.1, U714.3 (+)
unnamed: J1.1, U1.20 (RD1)
unnamed: J1.2, U1.19 (RD0)
unnamed: J1.3, U1.18 (RC3/SCK/SCL)
unnamed: J1.4, U1.17 (RC2/P1A/CCP1)
unnamed: J1.5, U1.16 (RC1/T1OSI/CCP2)
unnamed: J1.6, U1.15 (RC0/T1OSO/T1CKI)
unnamed: J2.1, U1.29 (RD6/P1C)
unnamed: J2.2, U1.28 (RD5/P1B)
unnamed: J2.3, U1.27 (RD4)
unnamed: J2.4, U1.26 (RC7/RX/DT)
unnamed: J2.5, U1.25 (RC6/TX/CK)
unnamed: J2.6, U1.24 (RC5/SDO)
unnamed: J2.7, U1.23 (RC4/SDI/SDA)
unnamed: J2.8, U1.22 (RD3)
unnamed: J2.9, U1.21 (RD2)
unnamed: J94.1, U1.10 (RE2/AN7)
unnamed: J94.2, U1.9 (RE1/AN6)
unnamed: J94.3, U1.8 (RE0/AN5)
unnamed: J94.4, U1.7 (RA5/AN4/*SS/C2OUT)
unnamed: J94.5, U1.6 (RA4/T0CKI/C1OUT)
unnamed: J94.6, U1.5 (RA3/AN3/VREF+/C1IN+)
unnamed: J99.1, U1.35 (RB2/AN8)
unnamed: J99.2, U1.34 (RB1/AN10/C12IN3-)
unnamed: J555.1, U1.1 (RE3/*MCLR/VPP)
unnamed: J555.4, U1.40 (RB7/ICSPDAT)
unnamed: J555.5, U1.39 (RB6/ICSPCLK)
unnamed: Q1.2 (B), R6.1
unnamed: R1.2, U1.33 (RB0/AN12/INT), U3.2 (IO)
unnamed: R4.2, R5.1
unnamed: R6.2, U1.30 (RD7/P1D)
unnamed: R3.2, R17.2, U714.2 (-)

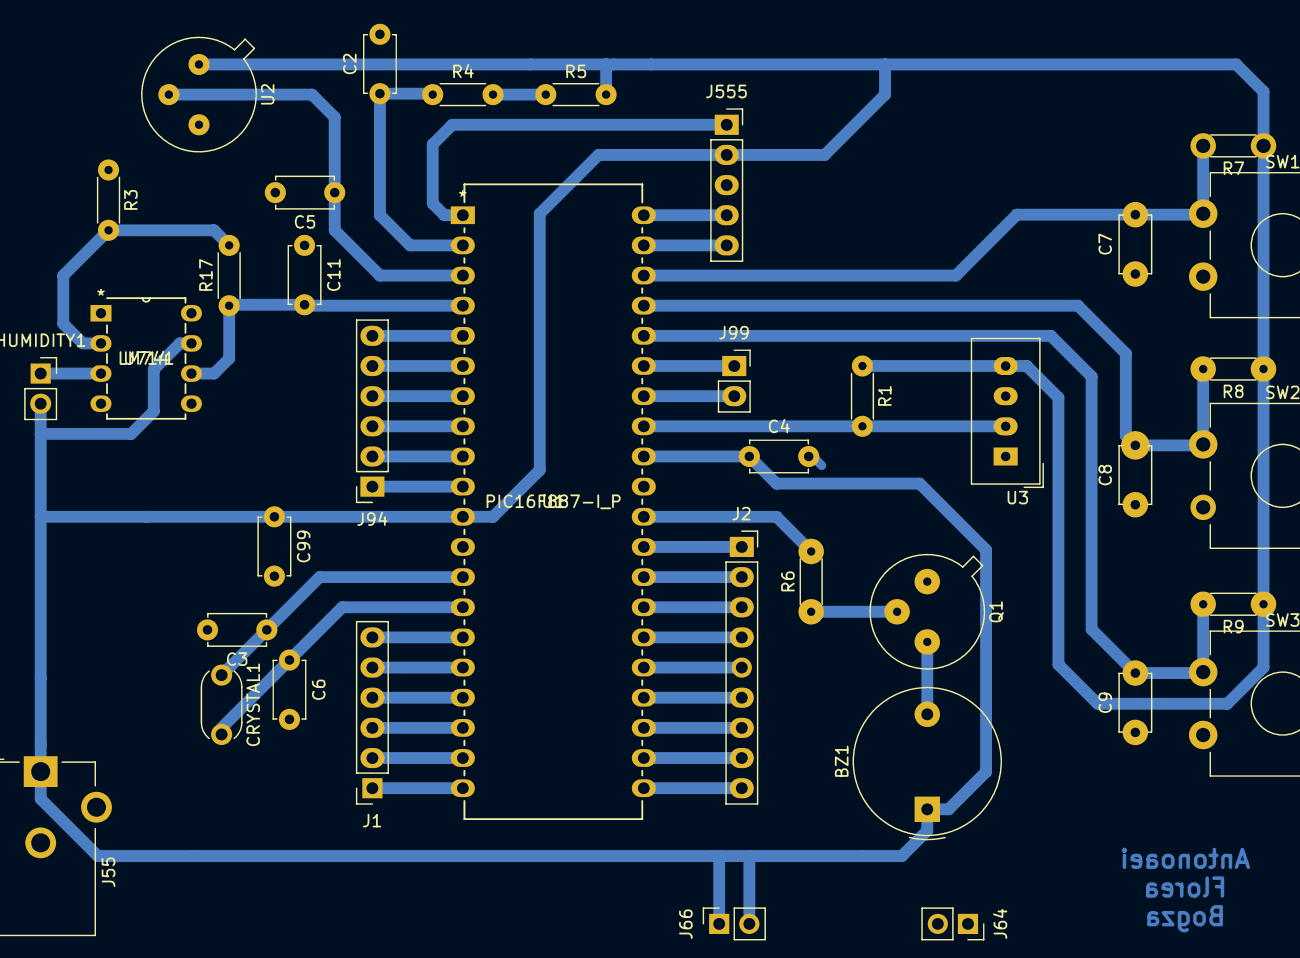
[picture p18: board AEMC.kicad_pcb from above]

Board: 2 copper layers, 38 parts (0 on the bottom side), 43 nets.

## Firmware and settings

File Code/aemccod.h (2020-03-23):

#include <xc.h> // include processor files - each processor file is guarded.  


unsigned char Citeste_ADC(unsigned char canal)
{
    ADCON0 = 0x00; //curat adcon0
    ADCON0 = (canal << 3); //selectam canal ADC, 3 biti ca sa ajungem pe bitii canalului
    ADON = 1; //seteaza bitul ADON din interiorul ADC sa fie ON
    
    delay(2000);//delay pt AD sa citeasca corect
        
    GODONE = 1;//porneste conversia
    while(GODONE);//pauza pana cand A/D termina conversia
    ADON = 0;//inchidem A/D
    return ADRESH;//returnez valoarea convertita
    
}
void main(void)
{
    float adctemp;
    float volt, temp;
    int c1, c2, c3, c4, temp1;
    ADCON1 = 0x10;// A/D Clock Fosc/8
    adctemp = Citeste_ADC(5)//citeste valoarea ADC pt lm35
    volt=adctemp * 4.88;
    temp = volt/10.0;
    //separam fiecare caracter ca sa il afisam pe lcd
    temp1 = temp*10;
    c1=(temp1/1000)%10;
    c2=(temp2/100)%10;
    c3=(temp3/10)%10;
    c4=(temp4/1)%10;
    
    
}

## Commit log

2020-03-16 Schema dupa meeting-ul de pe skype
2020-03-17 Add files via upload
    schematic changes-DONE
2020-03-21 Librarie PIC16F887
    Librarie PIC16F887 pentru KiCad
2020-03-23 Add files via upload
    updates sensors
2020-03-23 Schematic for PCB
    [AEMC.kicad_pcb, AEMC.sch]
2020-03-24 Layout cu trasee trase 24/03/2020
    [AEMC.kicad_pcb, AEMC.sch, Doarcomponentefarafire.kicad_pcb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]
2020-03-24 Liprarii pentru footprints (KiCad)
2020-03-24 Librarie KiCad (footprins)
2020-04-07 Modificare trasee, compactare componente
    Prima incercare de imprimare pe foaie
    [AEMC.kicad_pcb, AEMC.sch, Doarcomponentefarafire.kicad_pcb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]
2020-04-07 Add files via upload
    cod i2c+buzzer, kinda working, needs lcd.c file from the lab
2020-04-14 Update components footprints
    [AEMC.kicad_pcb, AEMC.sch, Doarcomponentefarafire.kicad_pcb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]
2020-04-28 Layout (sper sa fie bun si sa fie cel final)
    - Mici modificari pe ici pe colo
    - Am marit latimea traseelor (1mm)
    - Am marit pad-urile
    - Am stat si am verificat daca layout-ul corespunde cu dimensiunile componentelor
    - Am folosit multimetrul cumparat... sa masor rezistenta fotorezistorului in functie de intensitatea luminii
    - Am realizat practic imprimarea layout-ului pe placuta de cupru... (6-7 aproximativ)
    [AEMC.kicad_pcb, AEMC.sch, Doarcomponentefarafire.kicad_pcb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]

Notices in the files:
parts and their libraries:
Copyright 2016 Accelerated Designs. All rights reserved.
